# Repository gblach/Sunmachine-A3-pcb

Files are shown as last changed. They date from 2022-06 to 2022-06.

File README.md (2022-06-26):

# Sunmachine-A3-pcb
The driver for WS2812, SK6812 or similar LED strips controlled via Bluetooth LE.
It supports both RGB and WWA LEDs. This driver uses motion and light sensors, so in automatic mode
it can turn on the light when it detects someone's presence in the dark. The PCB is designed
for the [Hammond 1551V3](https://www.hammfg.com/electronics/small-case/plastic/1551v) enclosure,
so it can be hung on a wall or ceiling. The firmware for the board is available
in [Sunmachine-A3-fw](https://github.com/gblach/Sunmachine-A3-fw) repo and the mobile app
to control the board is available in [Sunmachine-app](https://github.com/gblach/Sunmachine-app)
repo.

## Key components
- [Raytac MDBT50-512K](https://www.raytac.com/product/ins.php?index_id=111) module with Nordic nRF52833 processor.
- RCWL-0516 microwave motion sensor.
- 5626 photodiode (5526 should work too).
- SN74LV1T34DBV level shifter.
- LM1117-3.3 voltage regulator.

## Connectors
- 2-pin ARK connector - for a power supply (5V).
- 3-pin ARK connector - for a LED strip (max. 6A).
- Tag-Connect 2050 - for a programmer.

## Production files
- [Gerber file](Sunmachine-A3.zip)
- [Bill of materials](Sunmachine-A3.csv)

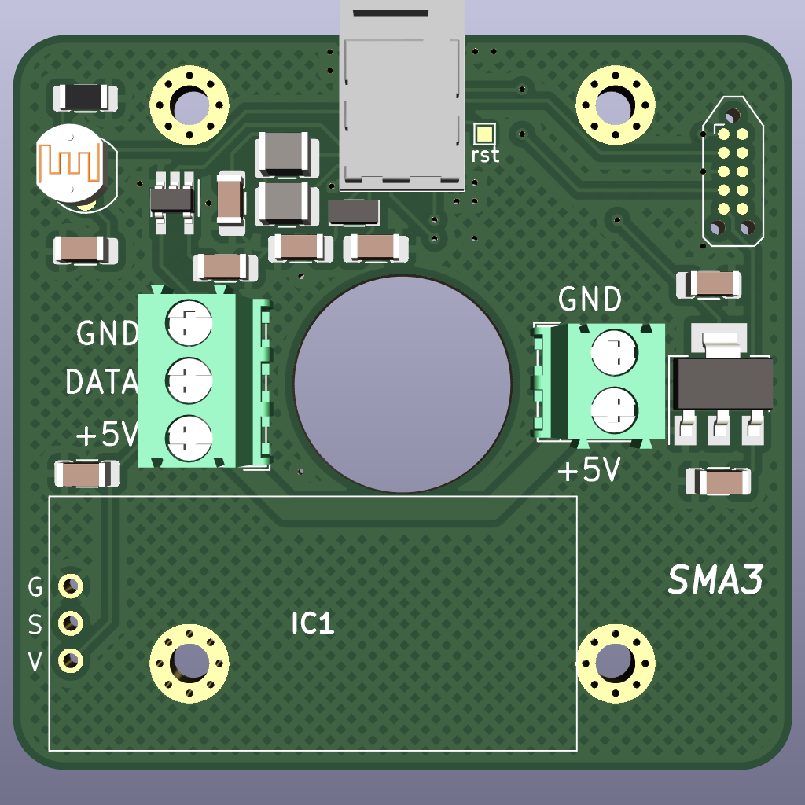
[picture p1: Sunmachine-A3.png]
PCB board


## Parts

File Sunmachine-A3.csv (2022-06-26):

Source: | /var/home/magik/collab/KiCad/Sunmachine-A3/Sunmachine-A3.kicad_sch
Date: | Sun 26 Jun 2022 18:28:46 CEST
Tool: | Eeschema 6.0.6
Generator: | /app/share/kicad/plugins/bom_csv_grouped_by_value_with_fp.py
Component Count: | 21
Ref | Qnty | Value | Cmp name | Footprint | Description | Vendor
C1, C2, C3, C4, C5, | 5 | 10uF | C_Small | Capacitor_SMD:C_1206_3216Metric_Pad1.33x1.80mm_HandSolder | Unpolarized capacitor, small symbol
C6, | 1 | 1uF | C_Small | Capacitor_SMD:C_1206_3216Metric_Pad1.33x1.80mm_HandSolder | Unpolarized capacitor, small symbol
C7, C8, | 2 | 12pF | C_Small | Capacitor_SMD:C_1206_3216Metric_Pad1.33x1.80mm_HandSolder | Unpolarized capacitor, small symbol
IC1, | 1 | RCWL-0516 | RCWL-0516 | RCWL-0516:RCWL-0516-3
J1, | 1 | Conn_02x05_Counter_Clockwise | Conn_02x05_Counter_Clockwise | Connector:Tag-Connect_TC2050-IDC-NL_2x05_P1.27mm_Vertical_with_bottom_clip | Generic connector, double row, 02x05, counter clockwise pin numbering scheme (similar to DIP packge numbering), script generated (kicad-library-utils/schlib/autogen/connector/)
J2, | 1 | Conn_01x02 | Conn_01x02 | TerminalBlock_4Ucon:TerminalBlock_4Ucon_1x02_P3.50mm_Horizontal | Generic connector, single row, 01x02, script generated (kicad-library-utils/schlib/autogen/connector/)
J3, | 1 | Conn_01x03 | Conn_01x03 | TerminalBlock_4Ucon:TerminalBlock_4Ucon_1x03_P3.50mm_Horizontal | Generic connector, single row, 01x03, script generated (kicad-library-utils/schlib/autogen/connector/)
L1, | 1 | 10uH | L_Small | Inductor_SMD:L_1210_3225Metric_Pad1.42x2.65mm_HandSolder | Inductor, small symbol
L2, | 1 | 15nH | L_Small | Inductor_SMD:L_1210_3225Metric_Pad1.42x2.65mm_HandSolder | Inductor, small symbol
R1, | 1 | 5626 | R_Photo | OptoDevice:R_LDR_5.1x4.3mm_P3.4mm_Vertical | Photoresistor
R2, | 1 | 10k | R | Resistor_SMD:R_1206_3216Metric_Pad1.30x1.75mm_HandSolder | Resistor
TP1, | 1 | reset | TestPoint | TestPoint:TestPoint_Pad_1.0x1.0mm | test point
U1, | 1 | MDBT50-512K | MDBT50-512K | Raytac:MDBT50 | Multiprotocol BLE/ANT/2.4 GHz/802.15.4 Cortex-M4F SoC, nRF52833 module
U2, | 1 | LM1117-3.3 | LM1117-3.3 | Package_TO_SOT_SMD:SOT-223-3_TabPin2 | 800mA Low-Dropout Linear Regulator, 3.3V fixed output, TO-220/TO-252/TO-263/SOT-223
U3, | 1 | SN74LV1T34DBV | SN74LV1T34DBV | Package_TO_SOT_SMD:SOT-23-5_HandSoldering | Single Power Supply, Single Buffer GATE, CMOS Logic, Level Shifter, SOT-23-5
Y1, | 1 | 32.768kHz, CL=9pF | Crystal_Small | Crystal:Crystal_SMD_3215-2Pin_3.2x1.5mm | Two pin crystal, small symbol

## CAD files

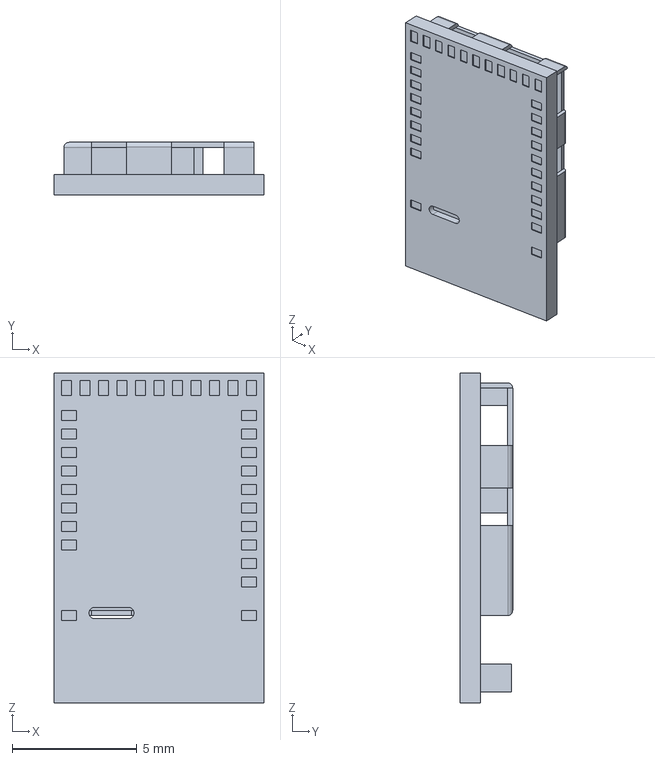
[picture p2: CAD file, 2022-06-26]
Raytac.models/mdbt50.stp
8.40 x 2.10 x 13.2 mm

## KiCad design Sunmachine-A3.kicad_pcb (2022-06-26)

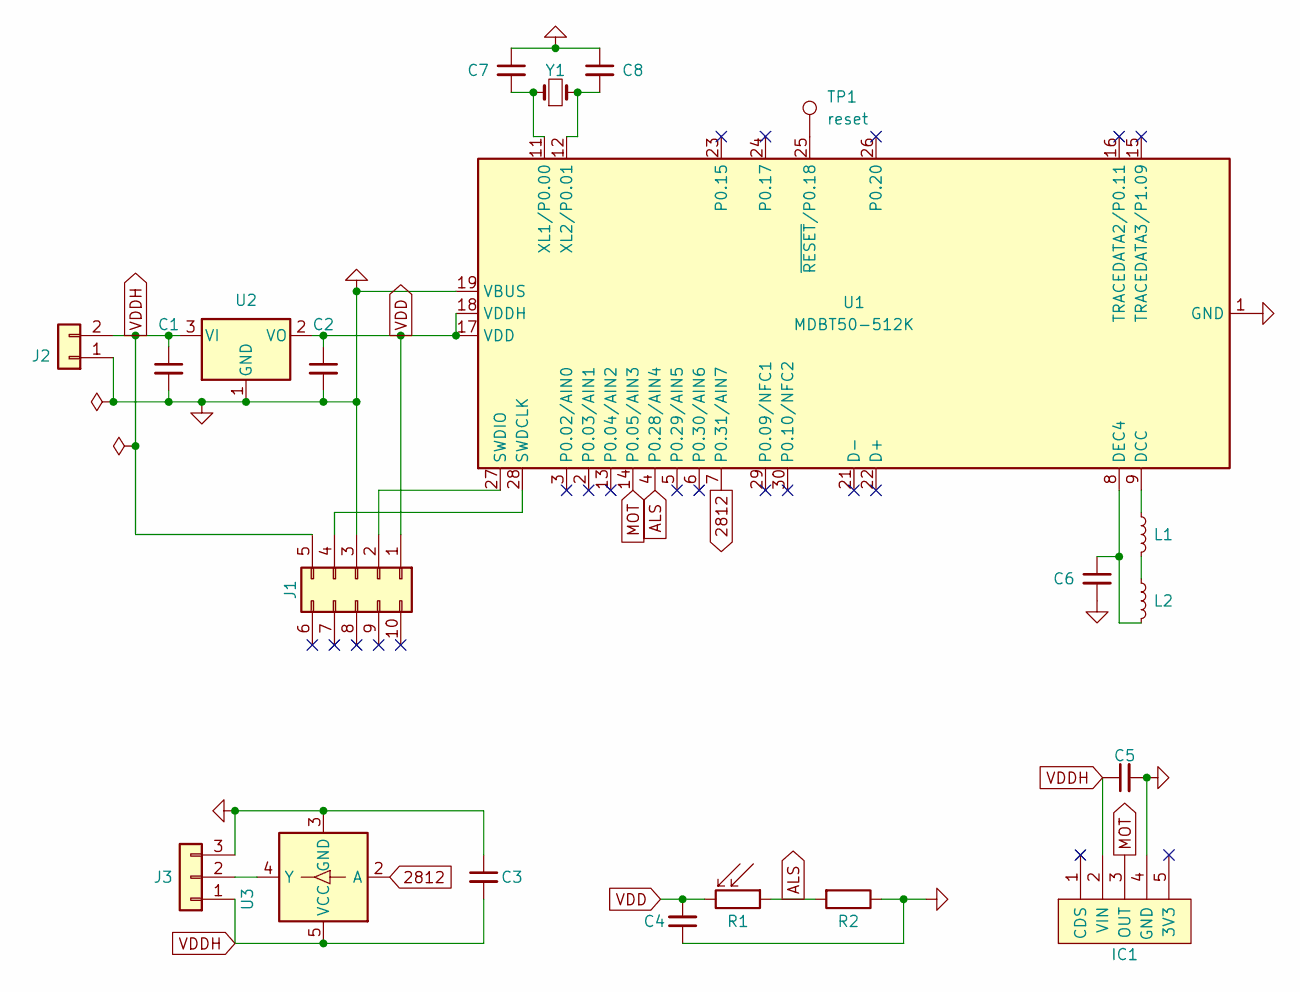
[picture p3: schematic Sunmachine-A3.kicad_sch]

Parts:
C1, C2, C3, C4, C5: 10uF; C_1206_3216Metric_Pad1.33x1.80mm_HandSolder; LCSC C15850
C6: 1uF; C_1206_3216Metric_Pad1.33x1.80mm_HandSolder
C7, C8: 12pF; C_1206_3216Metric_Pad1.33x1.80mm_HandSolder
IC1: RCWL-0516; RCWL-0516-3
J1: Conn_02x05_Counter_Clockwise; Tag-Connect_TC2050-IDC-NL_2x05_P1.27mm_Vertical_with_bottom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
J2: Conn_01x02; TerminalBlock_4Ucon_1x02_P3.50mm_Horizontal
J3: Conn_01x03; TerminalBlock_4Ucon_1x03_P3.50mm_Horizontal
L1: 10uH; L_1210_3225Metric_Pad1.42x2.65mm_HandSolder
L2: 15nH; L_1210_3225Metric_Pad1.42x2.65mm_HandSolder
R1: 5626; R_LDR_5.1x4.3mm_P3.4mm_Vertical
R2: 10k; R_1206_3216Metric_Pad1.30x1.75mm_HandSolder; LCSC C17902
TP1: reset; TestPoint_Pad_1.0x1.0mm
U1: MDBT50-512K; MDBT50
U2: LM1117-3.3; SOT-223-3_TabPin2; LCSC C6186
U3: SN74LV1T34DBV; SOT-23-5_HandSoldering; LCSC C100024
Y1: 32.768kHz, CL=9pF; Crystal_SMD_3215-2Pin_3.2x1.5mm

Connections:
2812: U1.7 (P0.31/AIN7), U3.2 (A)
ALS: R1.1, R2.2, U1.4 (P0.28/AIN4)
GND: C1.2, C2.2, C3.1, C4.1, C5.2, C6.2, C7.1, C8.1, IC1.4 (GND), J1.3, J2.1, J3.3, R2.1, U1.1 (GND), U1.10 (GND), U1.19 (VBUS), U1.20 (GND), U1.31 (GND), U2.1 (GND), U3.3 (GND)
MOT: IC1.3 (OUT), U1.14 (P0.05/AIN3)
unnamed: C6.1, L2.1, U1.8 (DEC4)
unnamed: C7.2, U1.11 (XL1/P0.00), Y1.1
unnamed: C8.2, U1.12 (XL2/P0.01), Y1.2
unnamed: J1.2, U1.27 (SWDIO)
unnamed: J1.4, U1.28 (SWDCLK)
unnamed: J3.2, U3.4 (Y)
unnamed: L1.1, L2.2
unnamed: L1.2, U1.9 (DCC)
unnamed 12: TP1.1, U1.25 (~RESET/P0.18); also elsewhere on the board
VDD: C2.1, C4.2, J1.1, R1.2, U1.17 (VDD), U1.18 (VDDH), U2.2 (VO)
VDDH: C1.1, C3.2, C5.1, IC1.2 (VIN), J1.5, J2.2, J3.1, U2.3 (VI), U3.5 (VCC)

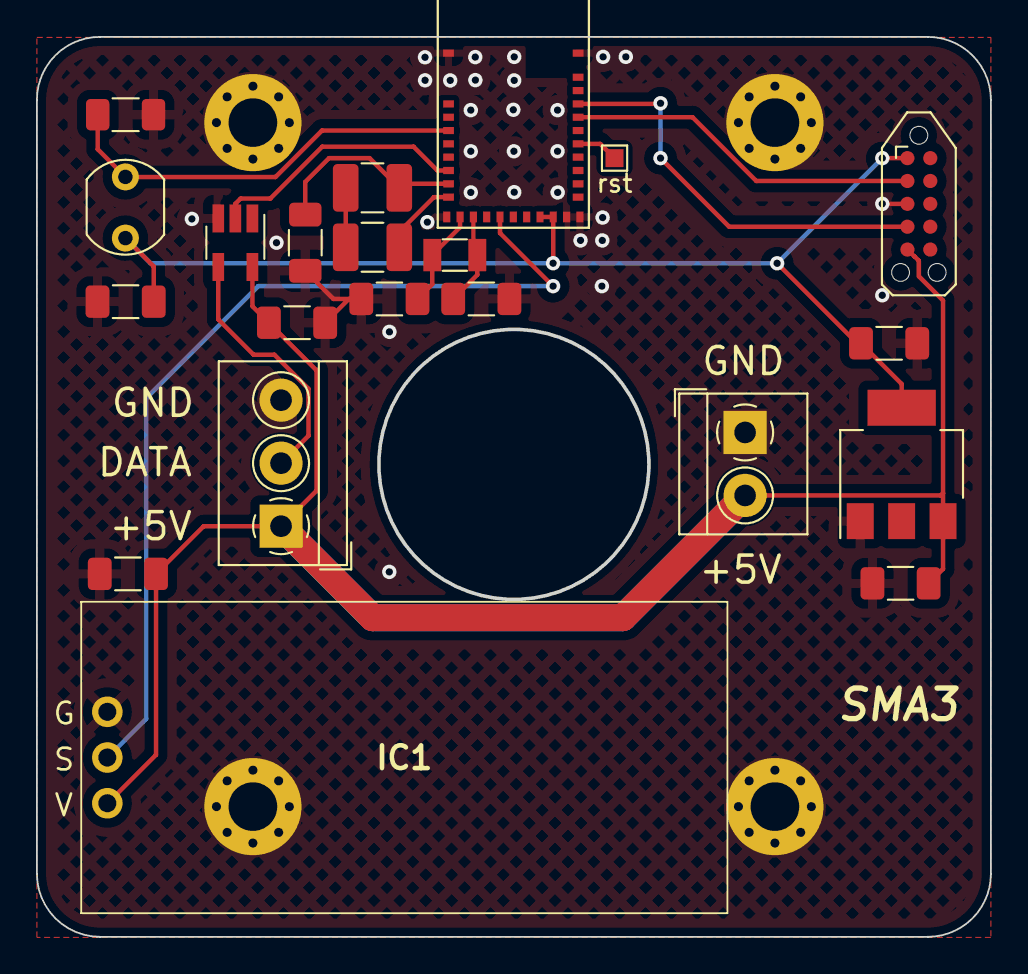
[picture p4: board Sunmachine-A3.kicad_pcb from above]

Board: 2 copper layers, 53.0 x 50.0 mm, 21 parts (0 on the bottom side), 15 nets.

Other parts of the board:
rst: reset; TestPoint_Pad_1.0x1.0mm

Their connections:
unnamed 12: rst.1; also elsewhere on the board
